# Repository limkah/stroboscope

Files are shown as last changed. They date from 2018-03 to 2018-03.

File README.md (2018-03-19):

# Stroboscope
Basic stroboscope implementation for measuring shaft/pulley RPM.

Prototype implementation is with P-channel power MOSFET driving a 12V high power LED as a high-side switch. Switching is done with a smaller N-channel MOSFET from the logic pin of a microcontroller (in this case an Arduino for the initial setup and testing). Display is going to be a 2x16 character display, since that's what I have in the parts bin, may switch to a 7 segment if I have to order parts.

Status:

- Basic board layout added for planning purposes.
- Added Rev 0 of firmware (functioning prototype).

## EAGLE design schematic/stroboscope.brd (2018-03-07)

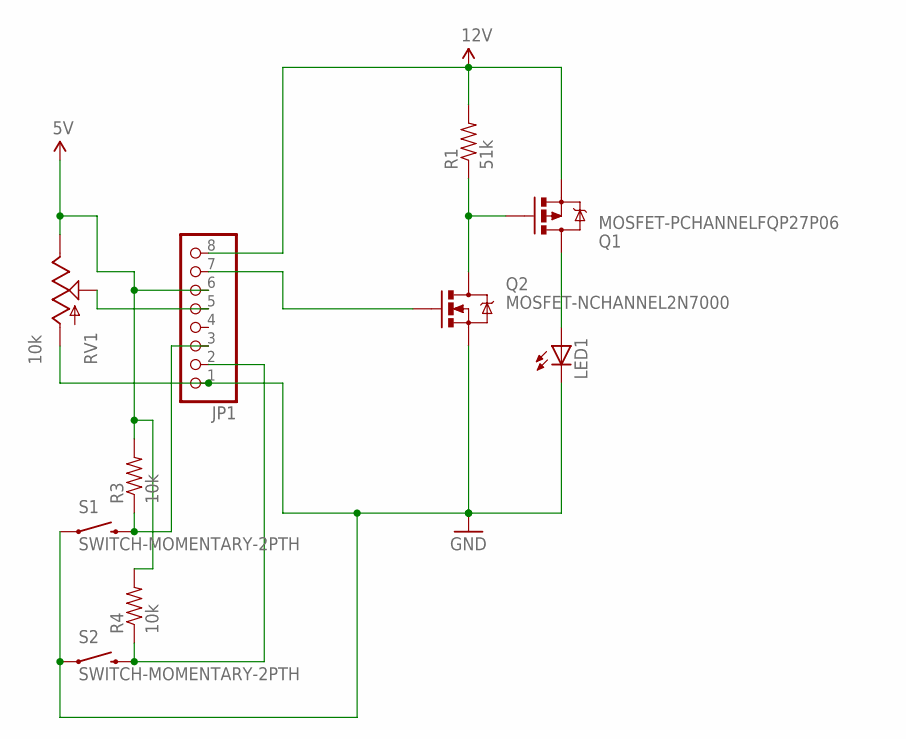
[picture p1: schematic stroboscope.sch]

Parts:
JP1: PINHD-1X8BIG; 1X08-BIG
LED1: LEDSQR2X5; LED2X5
Q1: MOSFET-PCHANNELFQP27P06; TO220V
Q2: MOSFET-NCHANNEL2N7000; TO-92
R1: 51k; AXIAL-0.4
R3, R4: 10k; AXIAL-0.4
RV1: 10k; ALPS_POT
S1, S2: SWITCH-MOMENTARY-2PTH; TACTILE-PTH

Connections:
5V: JP1.6, R3.P$2 (2), R4.P$2 (2), RV1.P$1 (E)
12V: JP1.8, Q1.3 (S), R1.P$2 (2)
GND: JP1.1, LED1.K (C), Q2.1 (S), RV1.P$3 (A), S1.1, S2.1
OUT: LED1.A, Q1.2 (D)
POT_SIG: JP1.5, RV1.P$2 (S)
PWR_GATE: Q1.1 (G), Q2.3 (D), R1.P$1 (1)
SIG: JP1.7, Q2.2 (G)
SW1_SIG: JP1.3, R3.P$1 (1), S1.3 (2)
SW2_SIG: JP1.2, R4.P$1 (1), S2.3 (2)

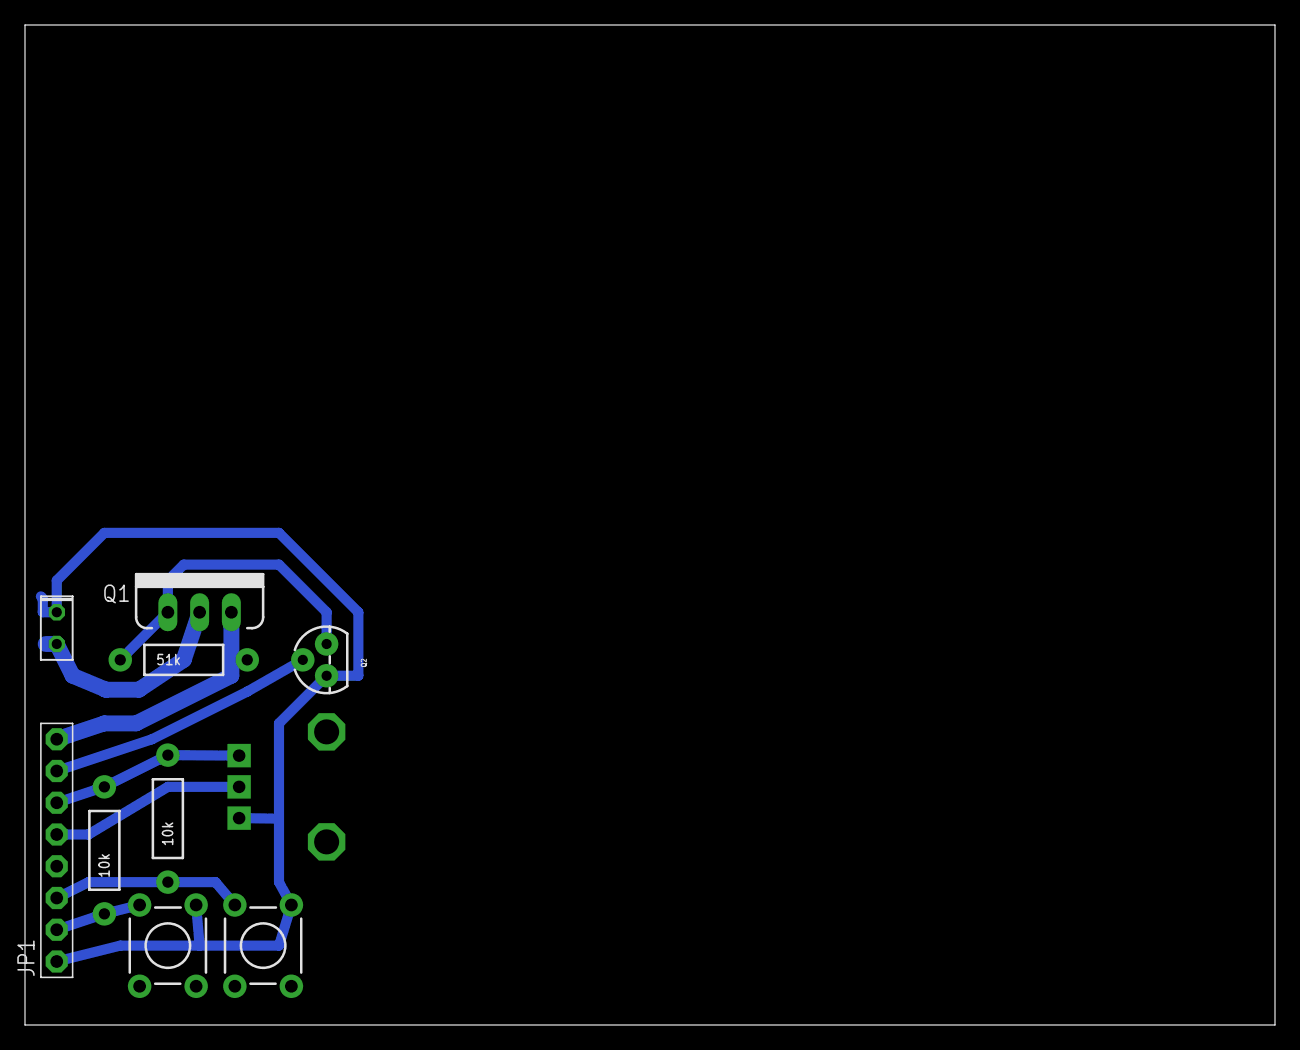
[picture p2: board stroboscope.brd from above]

Board: 2 copper layers, 100.0 x 80.0 mm, 10 parts (0 on the bottom side), 9 nets.

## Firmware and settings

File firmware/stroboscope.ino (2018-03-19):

#include <TimerOne.h>
#include <LiquidCrystal.h>

//Initialize libraries.
LiquidCrystal lcd(12, 11, 5, 4, 3, 2);

//Pin number definitions
int pot = A0; //Input for adjustment potentiometer.
int led = 9; //Output pin for LED on/off (gate of 2N7000 for P-chan MOSFET drive).
int up_sw = 7; //Input for RPM step increase switch.
int dw_sw = 6; //Input for RPM step decrease switch.

//Program variable definitions/initializatons
long rpm_to_us = 60 * 1000000; //60Hz/RPM * 1000000us/s, conversion factor to clean up code.
int rpm = 0; //Initialize RPM variable.
int rpm_step = 200;//Set step value for up/down switches.
int rpm_offset = 1000; //Set initial offset of RPM value.
int pos_rpm_cap = 4000; //Cap for RPM values, may remove this later.
int duty = 256; //Set 25% duty cycle by default.
long per = 0; //Initialize period variable.
int lp_counter = 0;
int lp_sp = 35;

void setup() {
  pinMode(up_sw, INPUT);
  pinMode(dw_sw, INPUT);
  pinMode(led, OUTPUT);
  pinMode(pot, INPUT);
  lcd.begin(16, 2); //Initialize 2 row, 16 character LCD display.
  Timer1.initialize(10000);//Initialize timer with a random frequency by default, because why not.
}

void loop() {
  //Read switches and adjust offset accordingly. Only allowing 1 update per loop() cycle.
  lp_counter++;

  if (lp_counter == lp_sp) {
    if (digitalRead(up_sw) == HIGH) {
      rpm_offset = rpm_offset + rpm_step;
      if (rpm_offset > pos_rpm_cap) {
        rpm_offset = pos_rpm_cap; //Cap RPM adjustment values.
      }
    } else if (digitalRead(dw_sw) == HIGH) {
      rpm_offset = rpm_offset - rpm_step;
      //Shouldn't need any checks because the offset will just stop at 0; int type variable.
    }
    lp_counter = 0;
  }

  rpm = (analogRead(pot)) + rpm_offset; //Read potentiometer and update RPM

  //Ensure RPM always remains positive.
  if (rpm < 1) {
    rpm = 1;
  }

  per = (rpm_to_us / rpm); //Convert RPM to period in us.
  Timer1.setPeriod(per);//Update timer period.
  Timer1.pwm(led, duty); //Update PWM on output pin.

  //Write RPM, period, and duty cycle values to display.
  lcd.setCursor(0, 0);
  lcd.print("RPM:");
  lcd.print(rpm);
  lcd.print("     ");
  lcd.setCursor(0, 1);
  lcd.print("P:");
  lcd.print(per / 1000); //period in ms
  lcd.print("ms ");
  lcd.print("D:");
  lcd.print((int)((duty * 100) / 1024));
  lcd.print("%");
  lcd.print("     ");

}

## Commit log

2018-03-07 Added initial version of schematic/board files
    Temporary layout for parts as an "extension" board for connection to an
    arduino or other dev kit. Does not represent a full, functional device,
    but just as a planning exercise. Will likely have the final circuit on
    perfboard with a bunch of auxilaries connected, since this will likely
    only be used a few times and doesn't need to be a polished device.
    [stroboscope.brd, stroboscope.sch]
2018-03-19 Added Rev 0 of Arduino firmware.
    Functioning initial implementation of the Arduino firmware (used on
    Arduino Uno), may update and clean up a few things, but it's mostly in
    its final form. Will likely be using a Teensy LC or smaller Arduino
    board, so may need to update some of the pin numbering. Corresponding
    update to schematic will be made when final board is decided on.

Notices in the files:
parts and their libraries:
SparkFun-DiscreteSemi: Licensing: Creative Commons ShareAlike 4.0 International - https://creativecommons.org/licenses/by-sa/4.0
